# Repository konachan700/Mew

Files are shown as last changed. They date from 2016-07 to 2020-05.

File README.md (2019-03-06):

## Mew - hardware password manager


 

*   [Forum](https://forum.mewhpm.com)
*   [Wiki](https://wiki.mewhpm.com)
*   [Code repo (github)](https://github.com/konachan700/Mew)
*   [Code repo (gitlab mirror)](https://gitlab.com/mewhpm/Mew)
*   [Hardware](https://easyeda.com/konachan.700/MeW_Pro_v2.1)
*	[Android app sources](https://github.com/konachan700/Mew/tree/master/software/MeWSync)

##### • What is it?
It's a small USB device to hold your passwords, private keys and cryptowallets.

*   Easy to use.
*   Fully open sourced.
*   No drivers or propietary software required.
*   Highly protected for critical data.

 

##### • How does it work?

Connect MeW to a PC or mobile device. Pair MeW with your smartphone via bluetooth. Install the MeW HPM app from Google Play or Appstore. Use it.  

_Demo video will be here a bit later :3_

12 passwords, those you use more often, can be entered directly on the device. Other passwords could be entered by MeW HPM app.  

_Demo video will be here a bit later :3_

You can exchange public keys with your friends directly via bluetooth.

Technically, it is a HID-keyboard.

Passwords are not stored in the device, all passwords are generated on-the-fly depending on the entered PIN-code and internal master key. Nobody and nothing can steal your passwords database, because there is none. If anybody steals the device, he can't bruteforce it - for each PIN-code the device generate different passwords, and, if you set this option, fake logins will be shown.  

Your private keys and wallets, that are stored on the device, are encrypted with AES-256. Encryption key is generated from master key and pin-code on-the-fly. Master key has been stored internally and can't be extracted, of course, if you set the maximum security level.

##### • I lost my MeW. How can I get my passwords back?

When you are starting your MeW for the first time with normal security level, the device key will shown. Save the device key at a secure place. MeW has a cloud backup for encrypted master keys. For recovery of your passwords on a new device you have to enter a device key in the application, and enter you PIN-code in MeW.

In the high security mode cloud backup will disabled, because in this mode the encrypted master key i can't be extracted from the device. If you lose your MeW or forgot a PIN-code, you loose all you passwords.

## • Android application screenshots
&nbsp;&nbsp;&nbsp;&nbsp;&nbsp;&nbsp;&nbsp;&nbsp;&nbsp;&nbsp;&nbsp;&nbsp;

## • Device photos
&nbsp;&nbsp;&nbsp;&nbsp;

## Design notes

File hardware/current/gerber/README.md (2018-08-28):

### MeW HPM :: Gerber files
Ready for production gerber files. 

### Where am I see this gerber?
https://gerber-viewer.easyeda.com/

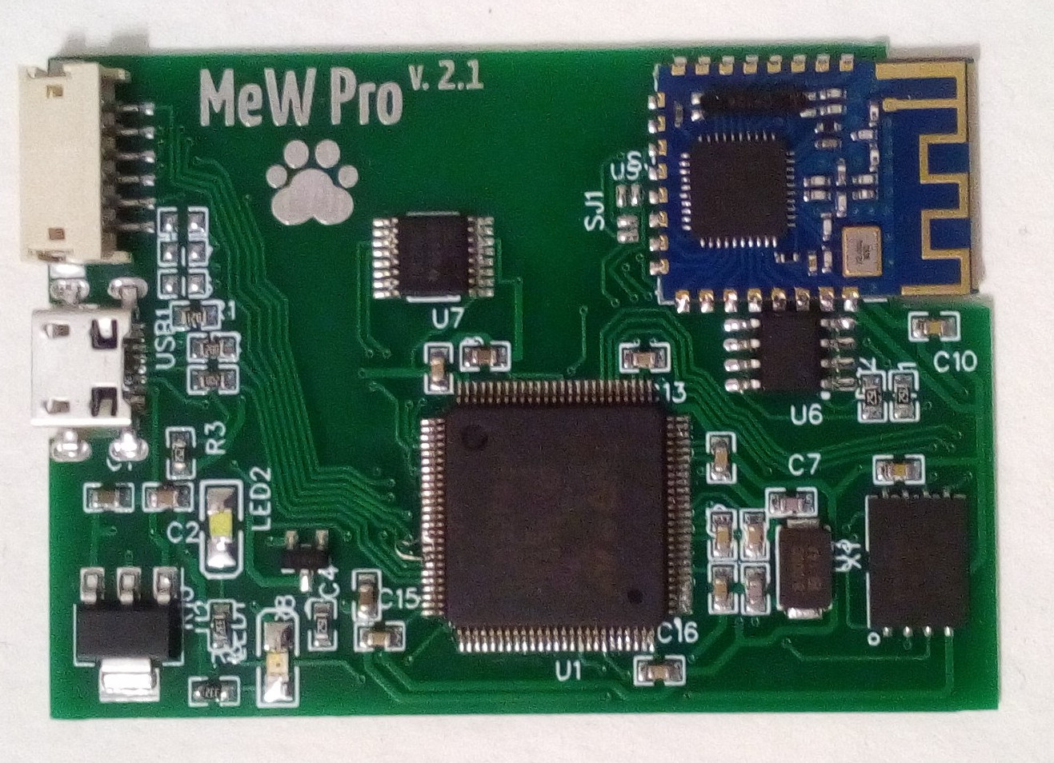
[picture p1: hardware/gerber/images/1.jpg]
Board image 1


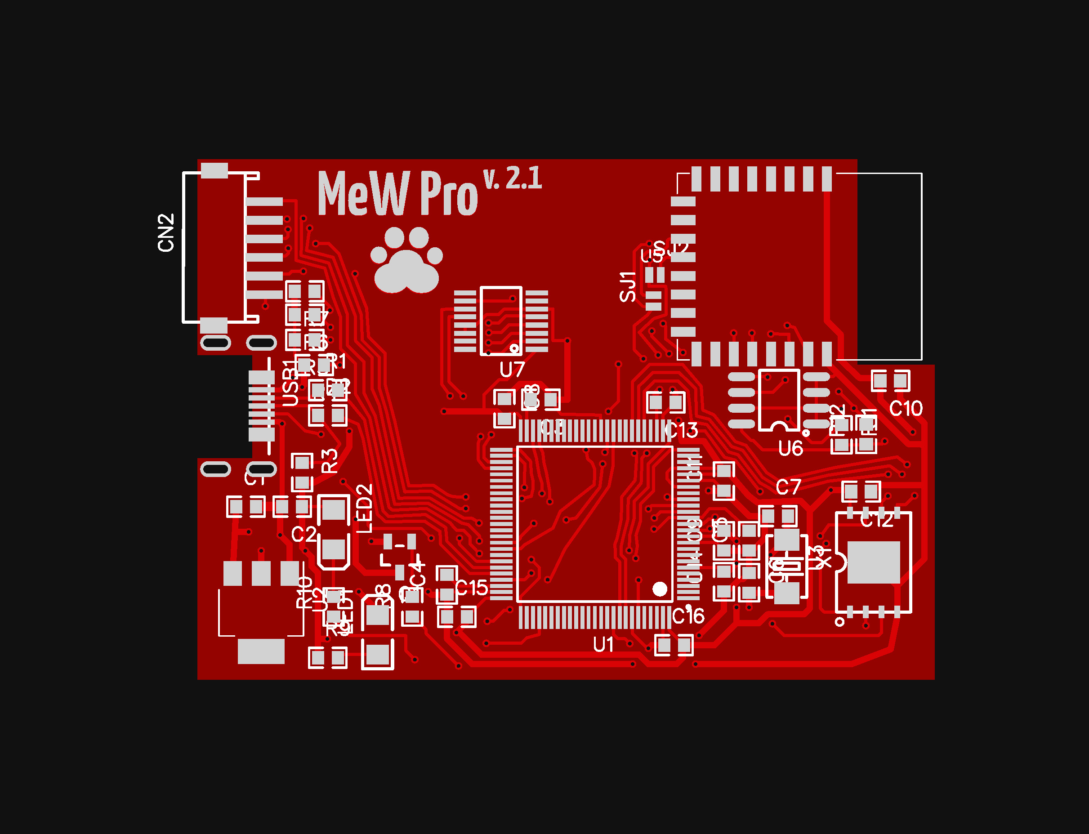
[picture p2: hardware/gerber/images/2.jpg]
Board image 2


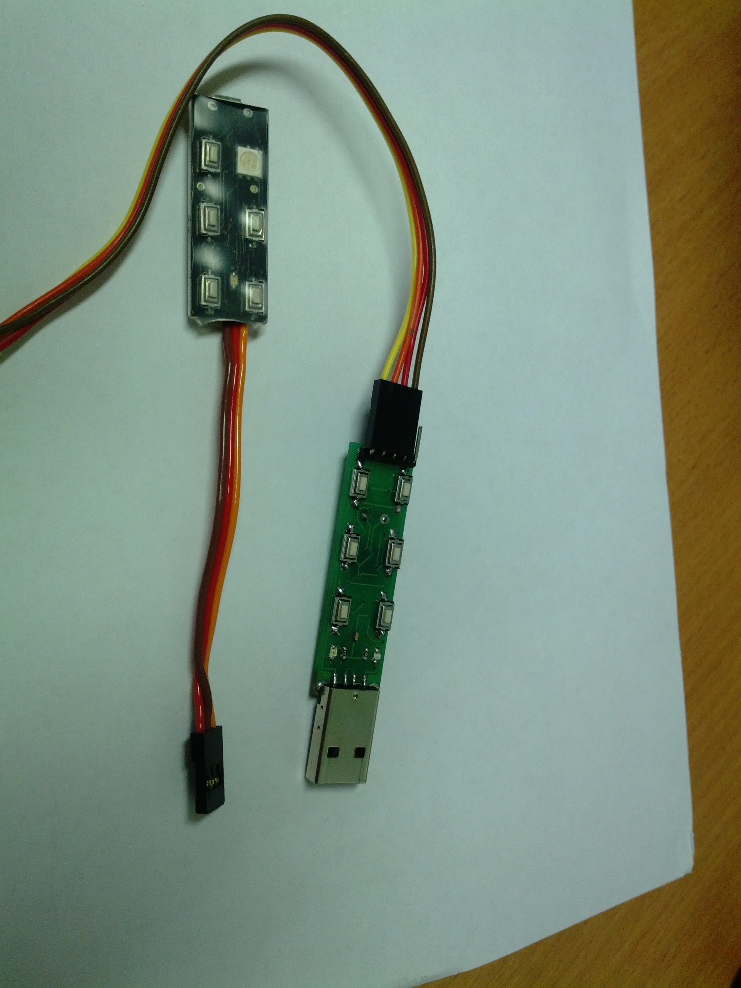
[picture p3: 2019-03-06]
promo/hardware/hw (3).jpg

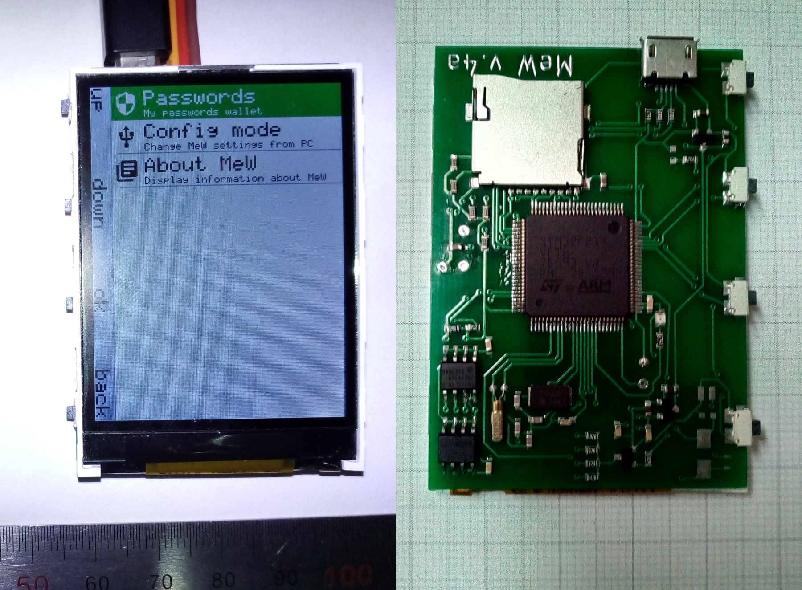
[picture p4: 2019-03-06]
promo/hardware/hw (1).jpg

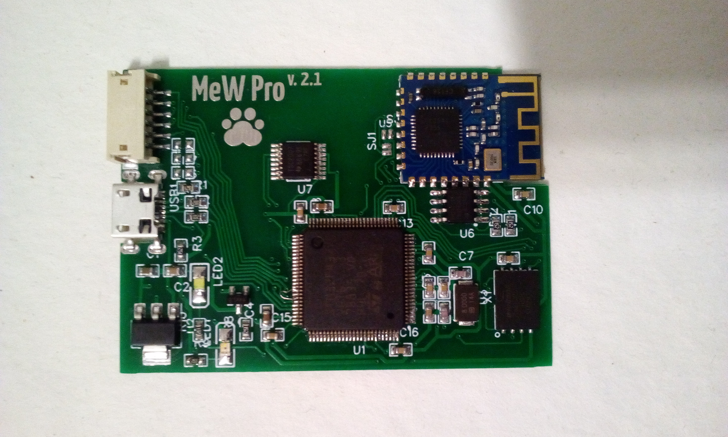
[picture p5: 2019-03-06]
promo/hardware/cameringo_20180814_204219.jpg

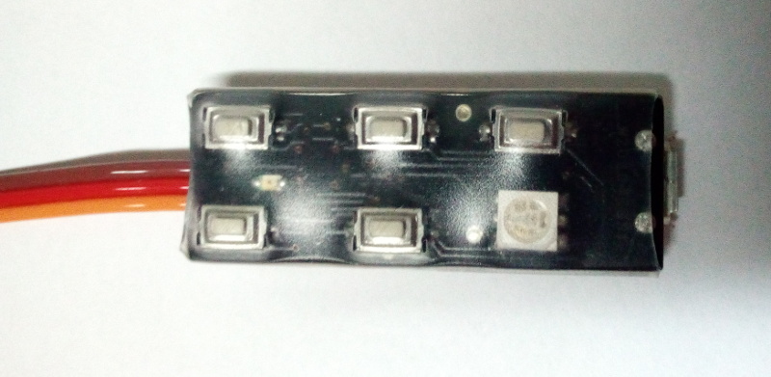
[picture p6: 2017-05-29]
promo/hardware/hw (4).jpg

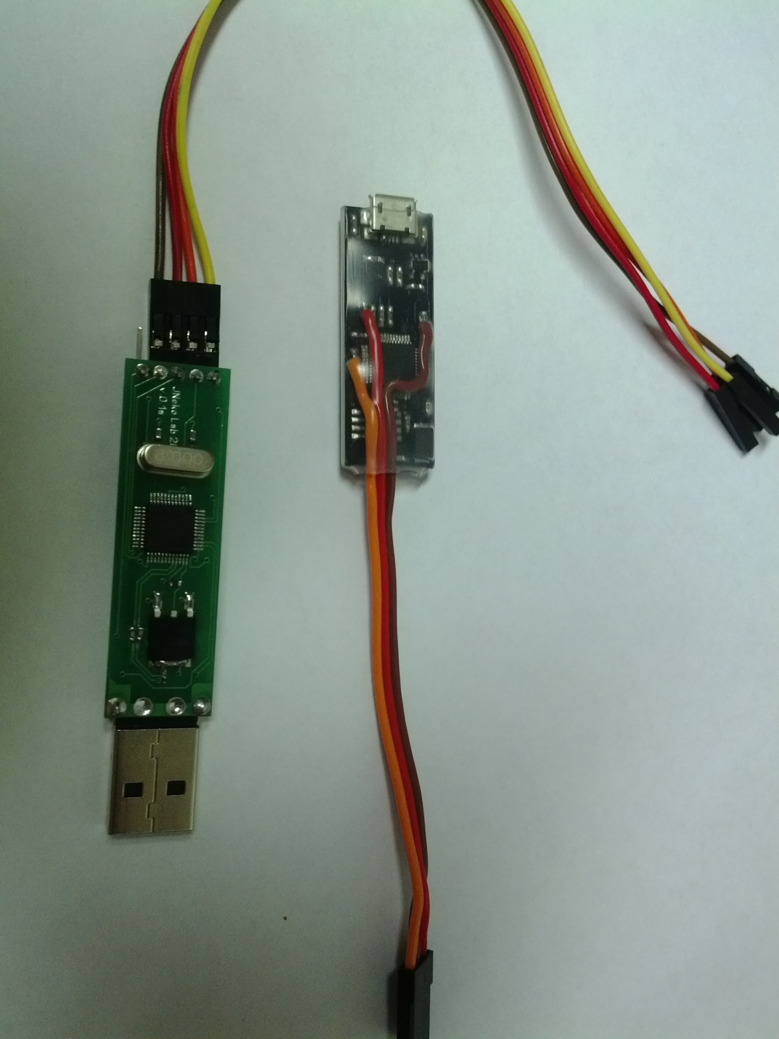
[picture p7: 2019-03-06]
promo/hardware/hw (2).jpg

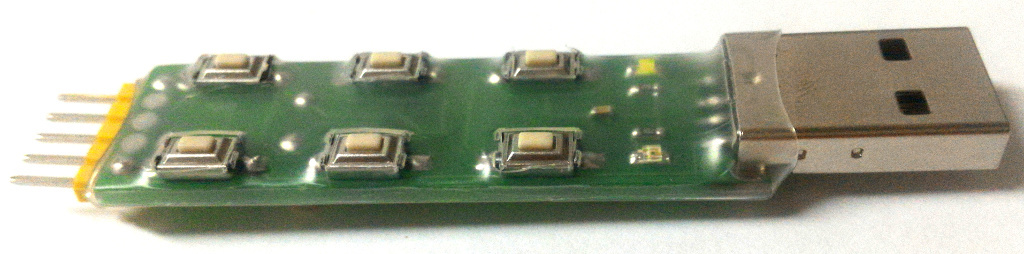
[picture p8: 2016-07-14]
promo/hardware/mewone-proto-01a.jpg

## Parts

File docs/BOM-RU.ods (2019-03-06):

В данном случае я считаю цену для покупки комплектухи поштучно в рознице. Оптовые цены, даже на небольших количествах (1000 штук) будут отличатся чуть ли не в 2-3 раза.
№ | Компонент | Модель | Кол-во | Цена, шт. | Цена, всего | Ссылка на магазин
MeW Pro A (Сенсорный экран, кнопки, bluetooth, батарея, 180MHz, 1M Rom, 256K Ram) || ЦЕНА РОЗНИЦЫ
1 | Контроллер | STM32F437VGT6 | 1 | р.1,050.00 | р.1,050.00 | https://www.electronshik.ru/item/ST/STM32F437VGT6
2 | Дисплей с сенсором | ILI9341 2.4' SPI 18Pin | 1 | р.313.04 | р.313.04 | https://www.aliexpress.com/item/2-4-Inch-240-320-SPI-Serial-TFT-LCD-Module-Display-With-Touch-Panel-Screen-ILI9341/32721841375.html
3 | Bluetooth | JDY-08 | 1 | р.112.00 | р.112.00 | https://www.aliexpress.com/item/10-pcs-JDY-08-BLE-Bluetooth-4-0-Uart-Transceiver-Module-CC2541-Central-Switching-Wireless-Module/32779065707.html
4 | Разьем карты памяти | NoName | 1 | р.7.69 | р.7.69 | https://www.aliexpress.com/item/10Pcs-TransFlash-TF-Micro-Memory-SD-Card-Self-eject-Socket-Plug-Adapter/32699668571.html
5 | Батарея LiIon | [L028] 3.7V 650mAh [303759] | 1 | р.79.38 | р.79.38 | https://www.aliexpress.com/item/L028-3-7V-620mAH-303759-PLIB-polymer-lithium-ion-battery-Li-ion-battery-for-bluetooth/711887876.html
6 | Micro USB Female Jack | NoName | 1 | р.3.21 | р.3.21 | https://www.aliexpress.com/item/100PCS-Lot-Micro-USB-Female-Jack-Socket-Connector-SMT-5Pin-5P-Long-feet-Gold-Plated/32735317426.html
7 | Выключатель питания* | MK12C02 7P-12608 | 1 | р.5.13 | р.5.13 | https://www.aliexpress.com/item/50PCS-Lot-MK12C02-7P-12608-MP3-MP4-Toggle-switch-Button-SMT-microswitch-KEY/32381680351.html
8 | Кнопки | 2 x 4 x 3.5mm | 5 | р.5.13 | р.25.65 | https://www.aliexpress.com/item/50pcs-2-x-4-x-3-5mm-Tact-Tactile-Push-Button-Switch-SMD-Surface-Mount-Momentary/32700051430.html
9 | Модуль зарядки батареи | TP4056 SOP-8 | 1 | р.4.49 | р.4.49 | https://www.aliexpress.com/item/200PCS-TP4056-SOP-TP4056E-SMD-new-and-original-IC/32874729556.html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
10 | Транзистор полевой | 2N7002K | 2 | р.2.57 | р.5.14 | https://www.aliexpress.com/item/Original-free-shipping-2N7002K-T1-E3-2N7002K-2N7002-SOT23-200PCS-LOT-in-Stock/32488438312.html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
11 | LDO | XC6206P332MR (уточнить) | 1 | р.1.29 | р.1.29 | https://www.aliexpress.com/item/100pcs-XC6206P332MR-XC6206P332-SOT23-XC6206-SMD-662K-3-3V-0-5A-SOT23-3-Positive-Fixed-LDO/32845735747.html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
12 | Резисторы** | (уточнить) | 10 | р.0.65 | р.6.50 | нет
13 | Конденсаторы** | (уточнить) | 10 | р.1.29 | р.12.90 | нет
14 | Светодиоды** | (уточнить) | 4 | р.0.65 | р.2.60 | нет
15 | Плата | NoName | 1 | р.12.41 | р.12.41 | нет
16 | Кварцевый резонатор | 8MHZ 5032 2P 8M | 1 | р.17.93 | р.17.93 | https://www.aliexpress.com/item/20PCS-8MHZ-5032-2P-8M-Crystal-5-3-2-2-feet/32841969827.html?priceBeautifyAB=0
17 | Кварцевый резонатор | 32.768KHz | 1 | р.3.85 | р.3.85 | https://www.aliexpress.com/item/100pcs-lot-Crystal-Cylinder-Cylinder-Clock-Crystal-Oscillator-32-768KHz-3x8MM-Passive-Quartz-Crystal-Resonator/1593653737.html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
ИТОГО |  |  |  |  | р.1,663.21
MeW Pro B (Сенсорный экран, кнопки, bluetooth, 168MHz, 1M Rom, 192K Ram) || ЦЕНА РОЗНИЦЫ
1 | Контроллер | STM32F407VGT6TR | 1 | р.582.00 | р.582.00 | https://www.electronshik.ru/item/ST/STM32F407VGT6TR
2 | Дисплей с сенсором | ILI9341 2.4' SPI 18Pin | 1 | р.313.04 | р.313.04 | https://www.aliexpress.com/item/2-4-Inch-240-320-SPI-Serial-TFT-LCD-Module-Display-With-Touch-Panel-Screen-ILI9341/32721841375.html
3 | Bluetooth | JDY-08 | 1 | р.112.00 | р.112.00 | https://www.aliexpress.com/item/10-pcs-JDY-08-BLE-Bluetooth-4-0-Uart-Transceiver-Module-CC2541-Central-Switching-Wireless-Module/32779065707.html
4 | Разьем карты памяти | NoName | 1 | р.7.69 | р.7.69 | https://www.aliexpress.com/item/10Pcs-TransFlash-TF-Micro-Memory-SD-Card-Self-eject-Socket-Plug-Adapter/32699668571.html
5 | Micro USB Female Jack | NoName | 1 | р.3.21 | р.3.21 | https://www.aliexpress.com/item/100PCS-Lot-Micro-USB-Female-Jack-Socket-Connector-SMT-5Pin-5P-Long-feet-Gold-Plated/32735317426.html
6 | Кнопки | 2 x 4 x 3.5mm | 5 | р.5.13 | р.25.65 | https://www.aliexpress.com/item/50pcs-2-x-4-x-3-5mm-Tact-Tactile-Push-Button-Switch-SMD-Surface-Mount-Momentary/32700051430.html
7 | Транзистор полевой | 2N7002K | 2 | р.2.57 | р.5.14 | https://www.aliexpress.com/item/Original-free-shipping-2N7002K-T1-E3-2N7002K-2N7002-SOT23-200PCS-LOT-in-Stock/32488438312.html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
8 | LDO | XC6206P332MR (уточнить) | 1 | р.1.29 | р.1.29 | https://www.aliexpress.com/item/100pcs-XC6206P332MR-XC6206P332-SOT23-XC6206-SMD-662K-3-3V-0-5A-SOT23-3-Positive-Fixed-LDO/32845735747.html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
9 | Резисторы** | (уточнить) | 7 | р.0.65 | р.4.55 | нет
10 | Конденсаторы** | (уточнить) | 7 | р.1.29 | р.9.03 | нет
11 | Светодиоды** | (уточнить) | 2 | р.0.65 | р.1.30 | нет
12 | Плата | NoName | 1 | р.12.41 | р.12.41 | нет
13 | Кварцевый резонатор | 8MHZ 5032 2P 8M | 1 | р.17.93 | р.17.93 | https://www.aliexpress.com/item/20PCS-8MHZ-5032-2P-8M-Crystal-5-3-2-2-feet/32841969827.html?priceBeautifyAB=0
ИТОГО |  |  |  |  | р.1,095.24
MeW Pro C (Сенсорный экран, кнопки, 168MHz, 1M Rom, 192K Ram) || ЦЕНА РОЗНИЦЫ
1 | Контроллер | STM32F407VGT6TR | 1 | р.582.00 | р.582.00 | https://www.electronshik.ru/item/ST/STM32F407VGT6TR
2 | Дисплей с сенсором | ILI9341 2.4' SPI 18Pin | 1 | р.313.04 | р.313.04 | https://www.aliexpress.com/item/2-4-Inch-240-320-SPI-Serial-TFT-LCD-Module-Display-With-Touch-Panel-Screen-ILI9341/32721841375.html
3 | Разьем карты памяти | NoName | 1 | р.7.69 | р.7.69 | https://www.aliexpress.com/item/10Pcs-TransFlash-TF-Micro-Memory-SD-Card-Self-eject-Socket-Plug-Adapter/32699668571.html
4 | Micro USB Female Jack | NoName | 1 | р.3.21 | р.3.21 | https://www.aliexpress.com/item/100PCS-Lot-Micro-USB-Female-Jack-Socket-Connector-SMT-5Pin-5P-Long-feet-Gold-Plated/32735317426.html
5 | Кнопки | 2 x 4 x 3.5mm | 5 | р.5.13 | р.25.65 | https://www.aliexpress.com/item/50pcs-2-x-4-x-3-5mm-Tact-Tactile-Push-Button-Switch-SMD-Surface-Mount-Momentary/32700051430.html
6 | Транзистор полевой | 2N7002K | 1 | р.2.57 | р.2.57 | https://www.aliexpress.com/item/Original-free-shipping-2N7002K-T1-E3-2N7002K-2N7002-SOT23-200PCS-LOT-in-Stock/32488438312.html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
7 | LDO | XC6206P332MR (уточнить) | 1 | р.1.29 | р.1.29 | https://www.aliexpress.com/item/100pcs-XC6206P332MR-XC6206P332-SOT23-XC6206-SMD-662K-3-3V-0-5A-SOT23-3-Positive-Fixed-LDO/32845735747.html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
8 | Резисторы** | (уточнить) | 5 | р.0.65 | р.3.25 | нет
9 | Конденсаторы** | (уточнить) | 5 | р.1.29 | р.6.45 | нет
10 | Светодиоды** | (уточнить) | 1 | р.0.65 | р.0.65 | нет
11 | Плата | NoName | 1 | р.12.41 | р.12.41 | нет
12 | Кварцевый резонатор | 8MHZ 5032 2P 8M | 1 | р.17.93 | р.17.93 | https://www.aliexpress.com/item/20PCS-8MHZ-5032-2P-8M-Crystal-5-3-2-2-feet/32841969827.html?priceBeautifyAB=0
ИТОГО |  |  |  |  | р.976.14
№ | Компонент | Модель | Кол-во | Цена, шт. | Цена, всего | Ссылка на магазин | № | Компонент | Модель | Кол-во | Цена, шт. | Цена, всего | Ссылка на магазин | № | Компонент | Модель | Кол-во | Цена, шт. | Цена, всего | Ссылка на магазин
MeW Pro A2 (Сенсорный экран, bluetooth, 180MHz, 1M Rom, 256K Ram, 128мб Flash) || ЦЕНА РОЗНИЦЫ |  |  |  |  |  |  | MeW Pro A (Сенсорный экран, кнопки, bluetooth, батарея, 180MHz, 1M Rom, 256K Ram) || ЦЕНА РОЗНИЦЫ |  |  |  |  |  |  | MeW Pro A (Сенсорный экран, кнопки, bluetooth, батарея, 180MHz, 1M Rom, 256K Ram) || ЦЕНА РОЗНИЦЫ
1 | Контроллер | STM32F437VGT6 | 1 | р.1,050.00 | р.1,050.00 | https://www.electronshik.ru/item/ST/STM32F437VGT6 | 1 | Контроллер | STM32F437VGT6 | 1 | р.1,050.00 | р.1,050.00 | https://www.electronshik.ru/item/ST/STM32F437VGT6 | 1 | Контроллер | STM32F437VGT6 | 1 | р.1,050.00 | р.1,050.00 | https://www.electronshik.ru/item/ST/STM32F437VGT6
2 | Дисплей с сенсором | ILI9341 2.4' SPI 18Pin | 1 | р.313.04 | р.313.04 | https://www.aliexpress.com/item/2-4-Inch-240-320-SPI-Serial-TFT-LCD-Module-Display-With-Touch-Panel-Screen-ILI9341/32721841375.html | 2 | Дисплей с сенсором | ILI9341 2.4' SPI 18Pin | 1 | р.313.04 | р.313.04 | https://www.aliexpress.com/item/2-4-Inch-240-320-SPI-Serial-TFT-LCD-Module-Display-With-Touch-Panel-Screen-ILI9341/32721841375.html | 2 | Дисплей с сенсором | ILI9341 2.4' SPI 18Pin | 1 | р.313.04 | р.313.04 | https://www.aliexpress.com/item/2-4-Inch-240-320-SPI-Serial-TFT-LCD-Module-Display-With-Touch-Panel-Screen-ILI9341/32721841375.html
3 | Bluetooth | JDY-08 | 1 | р.112.00 | р.112.00 | https://www.aliexpress.com/item/10-pcs-JDY-08-BLE-Bluetooth-4-0-Uart-Transceiver-Module-CC2541-Central-Switching-Wireless-Module/32779065707.html | 3 | Bluetooth | JDY-08 | 1 | р.112.00 | р.112.00 | https://www.aliexpress.com/item/10-pcs-JDY-08-BLE-Bluetooth-4-0-Uart-Transceiver-Module-CC2541-Central-Switching-Wireless-Module/32779065707.html | 3 | Bluetooth | JDY-08 | 1 | р.112.00 | р.112.00 | https://www.aliexpress.com/item/10-pcs-JDY-08-BLE-Bluetooth-4-0-Uart-Transceiver-Module-CC2541-Central-Switching-Wireless-Module/32779065707.html
4 | Micro USB Female Jack | NoName | 1 | р.3.21 | р.3.21 | https://www.aliexpress.com/item/100PCS-Lot-Micro-USB-Female-Jack-Socket-Connector-SMT-5Pin-5P-Long-feet-Gold-Plated/32735317426.html | 6 | Micro USB Female Jack | NoName | 1 | р.3.21 | р.3.21 | https://www.aliexpress.com/item/100PCS-Lot-Micro-USB-Female-Jack-Socket-Connector-SMT-5Pin-5P-Long-feet-Gold-Plated/32735317426.html | 6 | Micro USB Female Jack | NoName | 1 | р.3.21 | р.3.21 | https://www.aliexpress.com/item/100PCS-Lot-Micro-USB-Female-Jack-Socket-Connector-SMT-5Pin-5P-Long-feet-Gold-Plated/32735317426.html
5 | Транзистор полевой | 2N7002K | 2 | р.2.57 | р.5.14 | https://www.aliexpress.com/item/Original-free-shipping-2N7002K-T1-E3-2N7002K-2N7002-SOT23-200PCS-LOT-in-Stock/32488438312.html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 | 10 | Транзистор полевой | 2N7002K | 2 | р.2.57 | р.5.14 | https://www.aliexpress.com/item/Original-free-shipping-2N7002K-T1-E3-2N7002K-2N7002-SOT23-200PCS-LOT-in-Stock/32488438312.html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 | 10 | Транзистор полевой | 2N7002K | 2 | р.2.57 | р.5.14 | https://www.aliexpress.com/item/Original-free-shipping-2N7002K-T1-E3-2N7002K-2N7002-SOT23-200PCS-LOT-in-Stock/32488438312.html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
6 | LDO | AMS11133 | 1 | р.7.29 | р.7.29 |  | 11 | LDO | XC6206P332MR (уточнить) | 1 | р.1.29 | р.1.29 | https://www.aliexpress.com/item/100pcs-XC6206P332MR-XC6206P332-SOT23-XC6206-SMD-662K-3-3V-0-5A-SOT23-3-Positive-Fixed-LDO/32845735747.html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 | 11 | LDO | XC6206P332MR (уточнить) | 1 | р.1.29 | р.1.29 | https://www.aliexpress.com/item/100pcs-XC6206P332MR-XC6206P332-SOT23-XC6206-SMD-662K-3-3V-0-5A-SOT23-3-Positive-Fixed-LDO/32845735747.html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
7 | Резисторы** | (уточнить) | 10 | р.0.65 | р.6.50 | нет | 12 | Резисторы** | (уточнить) | 10 | р.0.65 | р.6.50 | нет | 12 | Резисторы** | (уточнить) | 10 | р.0.65 | р.6.50 | нет
8 | Конденсаторы** | (уточнить) | 10 | р.1.29 | р.12.90 | нет | 13 | Конденсаторы** | (уточнить) | 10 | р.1.29 | р.12.90 | нет | 13 | Конденсаторы** | (уточнить) | 10 | р.1.29 | р.12.90 | нет
9 | Светодиоды** | (уточнить) | 4 | р.0.65 | р.2.60 | нет | 14 | Светодиоды** | (уточнить) | 4 | р.0.65 | р.2.60 | нет | 14 | Светодиоды** | (уточнить) | 4 | р.0.65 | р.2.60 | нет
10 | Плата | NoName | 1 | р.12.41 | р.12.41 | нет | 15 | Плата | NoName | 1 | р.12.41 | р.12.41 | нет | 15 | Плата | NoName | 1 | р.12.41 | р.12.41 | нет
11 | Кварцевый резонатор | 8MHZ 5032 2P 8M | 1 | р.17.93 | р.17.93 | https://www.aliexpress.com/item/20PCS-8MHZ-5032-2P-8M-Crystal-5-3-2-2-feet/32841969827.html?priceBeautifyAB=0 | 16 | Кварцевый резонатор | 8MHZ 5032 2P 8M | 1 | р.17.93 | р.17.93 | https://www.aliexpress.com/item/20PCS-8MHZ-5032-2P-8M-Crystal-5-3-2-2-feet/32841969827.html?priceBeautifyAB=0 | 16 | Кварцевый резонатор | 8MHZ 5032 2P 8M | 1 | р.17.93 | р.17.93 | https://www.aliexpress.com/item/20PCS-8MHZ-5032-2P-8M-Crystal-5-3-2-2-feet/32841969827.html?priceBeautifyAB=0
12 | Модуль памяти 128мб |  | 1 | р.145.00 | р.145.00
13 | Контроллер сенсорного экрана |  | 1 | р.80.00 | р.80.00
ИТОГО |  |  |  |  | р.1,543.02 |  | ИТОГО |  |  |  |  | р.1,537.02 |  | ИТОГО |  |  |  |  | р.1,537.02

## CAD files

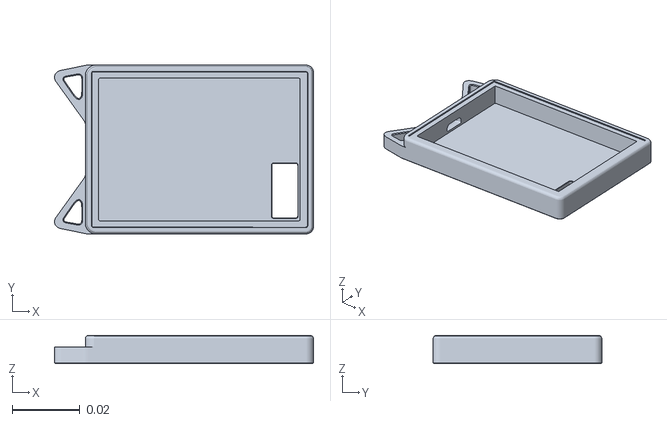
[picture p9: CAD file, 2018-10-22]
case/Case_mewboard_b.stl
0.0767 x 0.05 x 0.00832

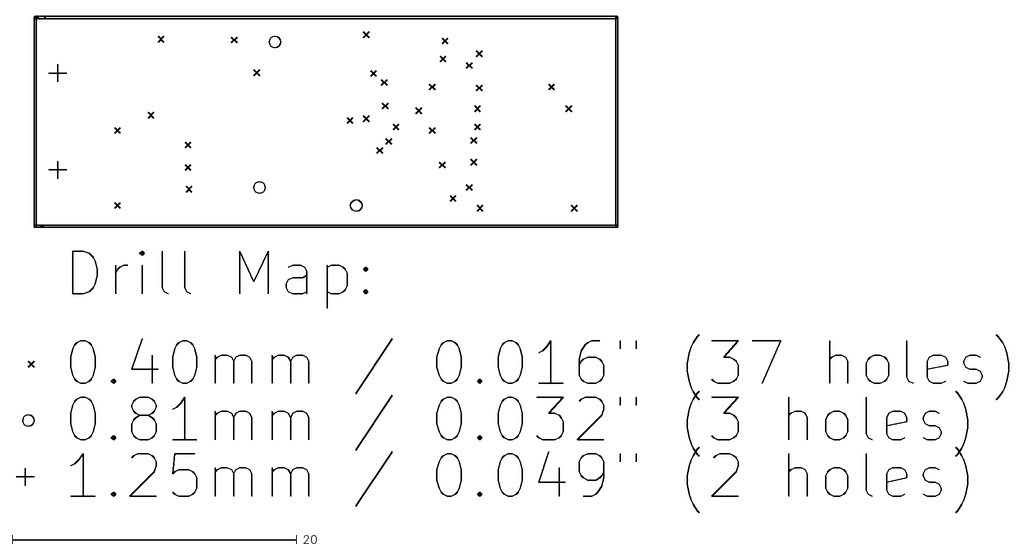
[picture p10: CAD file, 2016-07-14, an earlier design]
hardware/old-mew-one/kiCad/__test-drl_map.dxf
69.7 x 34.8

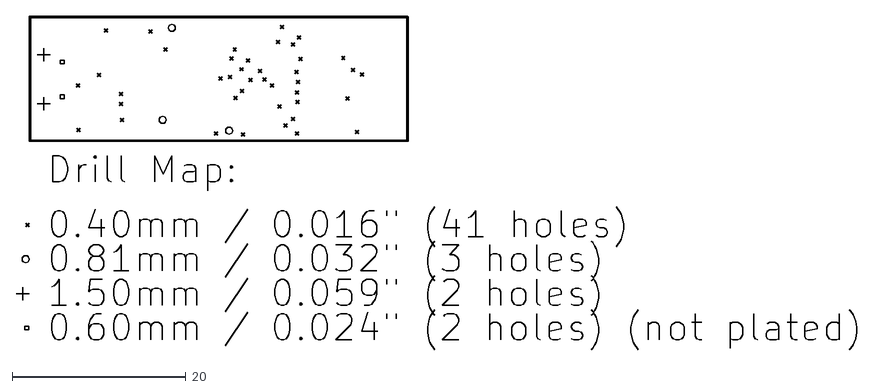
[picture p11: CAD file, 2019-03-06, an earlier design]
hardware/old-mew-one/kiCad/board_mew2/__test-drl_map.dxf
96.8 x 38.4

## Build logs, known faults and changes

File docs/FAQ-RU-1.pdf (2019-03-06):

Общий FAQ по техническому устройству.

Q: Можно ли приделать сканер отпечатков?
A: Можно. Однако есть проблемы.
1. Сканеров свободного назначения в продаже как-то не густо, и почти все они -огромные по размерам, предназначенные для установки на объектовых КПП. От телефонов поставить нельзя, документацию на него нам никто не даст, а без документации для написания драйверов это просто кусок пластмассы.
2. Безопасность бытовых сканеров отпечатков нулевая. Подделать отпечаток при наличии навыков задача очень простая.
3. Сканер отдает картинку. Обработка и сравнение отпечатка - очень сложная высшая математика, кода очень много. Часть можно взять из библиотек линукса, но в любом случае работы там очень много.

Q: Можно ли заменить нашим устройством токены для банк-клиентов?
A: Теоретически да. Технически все необходимое там есть. Но для такого токена нужна сертификация и куча лицензий от всех возможных регуляторов - иначе банк справедливо пошлет лесом самоделкиных.
Основа банковских токенов - доверие разработчику и ЦС. Рынок очень закрытый и консервативный по понятным причинам - какое доверие на проходном дворе? На старте сюда лезть полностью бесполезно.

Q: Почему нужно отдельное устройство? Почему не сделать приложение на телефон? A: Несколько проблем.
1. На андроид сделать такое приложение можно. Но для него нужен рут и сборка драйверов под конкретное ядро (то есть под конкретную модель телефона). Гемор страшный. На остальные устройства такое прикрутить нельзя.
2. Телефоны дырявы насквозь, и по ним не шарится только совсем ленивый. Даже для брендов, исключая разве что Apple, драйвера пишет индус за доллар в день - качество там ниже плинтуса, ехала уязвимость через уязвимость. Хакеры и спецслужбы могут отломить любой телефон и угнать базу паролей при первом желании. Какой смысл держать пароли в таком ненадежном месте?

Q: Зачем карта памяти? Почему не nand/eMMC?
A: Во-первых, хранить пароли, кошельки, другую инфу. Даже если устройство навернулось, мы можем переставить карту в другое и продолжать пользоваться. Данные зашифрованы, и такая операция безопасна. Во-вторых, карта стоит дешевле той же eMMC аналогичного размера, и на прототипах куда проще поставить карту, а не паять BGA.

Q: Сколько паролей влезает?
A: Для версий с картой - сколько угодно. Для простой версии - по количеству кнопок.

Q: Везде ли поддерживается?
A: Да, везде. По крайней мере там, где есть поддержка USB HID - а это любое устройство: телефон, игровая приставка, ТВ-приставка, ПК, Raspberry Pi, и прочее оборудование. Надо уточнять, однако, насчет телефонов Apple - возможно, нужен будет специальный переходник.

Q: Что понимать под поддержкой?
A: Принцип “устройство как сервис”
1. Есть две прошивки - одна открытая от сообщества, другая фирменная. Технически они почти одинаковы, но та, которая открытая, с официальными серверами не синхронизируется. Можно поднять свой сервер, но это реально будут делать 1 из 10 тысяч.
2. Синхронизация официальных устройств с сервером. Там хранится зашифрованная на пароль пользователя база, и ее кража для хакеров полностью бессмысленна.
3. Создание и поддержка SDK для написания приложений под официальную версию - чтобы самим не морочить голову написанием кошельков для криптовалют.
4. Приложения под все мобильные платформы и на десктоп.

Q: Какой функционал планируется в идеале?
A: Большой =)
1. Аппаратный менеджер паролей
2. Имитатор CD-ROM для установки ОС (если позволит скорость чипа)
3. Маленькая защищенная флешка
4. Неизвлекаемое хранилище
5. Цифровая подпись, совместимая с OpenSSL
6. Шифрование RSA и AES для различных нужд
7. TOTP
8. Криптовалютные кошельки
9. Тамагочи (шутка)

Q: А че такой похабный экран? Где IPS?
A: Хороших экранов в рознице нет, видимо, они поштучно никому не нужны. Все хорошие дисплеи от 4 дюймов размером, что для нашего устройства перебор. Есть маленькие oled, но стоят они очень дорого и не комплектуются сенсорными панелями. Если взлетит - можно поковырять алибабу и поискать приличный дисплей, сейчас обойдемся обычным TFT.

Q: Можно ли заказать 2-3 штуки плат для тестов?
A: Можно. Но сэкономить не выйдет.
1. Платы что 2, что 10 стоят одинаково 2 бакса
2. Под плату нужен трафарет, стальной лист 20 х 30. Без него запайка превращается в производство брака. Я с трудом запаял без трафарета маленькую версию, большую вообще не реально запаять, не перегрев всё подряд.
3. Заказ делается неделю и идет месяц-полтора.
UPD 31-05-18: Платы и трафареты подешевели, комплект с доставкой стоит $20.

Q: Не украдут ли китайцы? Какую защиту прикрутить?
A: Обязательно украдут. Это неизбежно и сделать ничего нельзя: чувак на хабре вон ради шутки сделал абсолютно бесполезный usb-killer для порчи портов - так через год оно на али появилось в куче мест. Зачем? Китаец увидел - китаец сделал, а рынок сам определит зачем. Потому надо изначально понять, как от китайских клонов получить выгоду, а не убыток. Прикручивать защиту бесполезно, даже вредно: китаец просто сделает аналог, а не клон, и тогда профит с него не поиметь никак.

Q: Что такое индексы A, B, C у MeW Pro?
A: Плата изначально была запроектирована универсальной. Различия такие:
1. Модель A. Максимальная, есть все оборудование. Эта модель основная.
2. Модель B. Без батареи и с более слабым контроллером (но незначительно). Батарея не сильно нужна в большинстве применений такого устройства, потому аппарат без нее имеет право на существование.
3. Модель C. Это модель B, но без bluetooth. Опять же, многим он не нужен.

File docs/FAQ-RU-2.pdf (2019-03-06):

Общий FAQ по использованию устройства.

Q: Я потерял устройство. Другой его нашел. Что делать?
A: Моделей защиты несколько, они будут выбиратся:
1. Пароли на устройстве создаются “на лету” из пин-кода пользователя и внутреннего ключа при помощи алгоритмов хеширования. То есть от каждого возможного пин-кода будет свой пароль. Нашедший устройство просто не будет знать, какой пин-кода верный, устройство для всех пин-кодов отдает пароли, но для неверного пин-кода будет и пароль неправильный. Эта модель позволяет иметь несколько банок паролей на одном устройстве, вводя разные пин-коды.
2. Тоже самое, что в п.1, но ключа уже два: для правильного пин-кода и для остальных. Дополнительно в устройстве сохраняется хеш правильного пин-кода. Дальше, например, при 4 попытках неверного ввода устройство изменит ключ правильного пин-кода, от которого создавались пароли - даже если злоумышленник угадает пин-код перебором, пароли он получит неправильные.
3. Просто пин-код и 3 попытки его ввода. Не угадал - ключ стерся.

Q: Меня взяли за задницу преступники, и они просят пин-код. Что делать?
A: Устройство имеет пин-коды для полного стирания памяти. Их набор гарантированно сменит пароли, после чего можно будет отдать настоящий пин-код - твоих паролей там не будет, да и привязка к облаку отвалится. Если такое устройство попробовать синхронизировать без сброса в аккаунте - бекап будет заблокирован.

Q: У меня в почте зашифрованная переписка, содержащая неоднозначные или не одобряемые обществом вещи. Кто-то из родственников может знать мой пин-код, подсмотрев набор. Как быть?
A: Устройство поддерживает динамические пин-коды:
1. Каждый раз разный пин-код, метод генерации которого задается в настройках. Например, сегодня 1.01 и пинкод будет 777101, а завтра он будет 777201. Пусть подглядывают.
2. Пин-код из большого набора изображений, из которых надо выделить тег. Например, 16 картинок котят, в которых надо тапнуть по порядку только белых с черным пятном. Поскольку никто не знает, по какому принципу идет выборка котят, отгадать такой пин-код подсмотревшему почти невозможно - картинок котят всего 256 штук и выводятся они случайно по 16 штук.

Q: Я укурился\набухался и боюсь, что начну использовать устройство в нетрезвом виде. Как быть?
A: Устройство имеет временную блокировку от использования. Устройство отключается специальным пин-кодом и восстанавливается только в установленное время после синхронизации с облаком.

Q: Я имею очень важные или секретные данные, которые даже зашифрованными нельзя класть в облако. Как быть?
A: Устройство имеет несколько уровней безопасности:
1. Параноидальный. Динамический пин-код с двумя попытками ввода. Синхронизация с облаком отключена, ключ шифрования памяти использует пин-код и внутренний ключ. Флешка дополнительно запаролена аппаратно, то есть снять с нее даже зашифрованный бекап нельзя - для любого другого устройства она выглядит как неисправная. При любой тревоге (введен пин-код стирания, неверный ввод пин-кода) происходит не только стирание ключей, но и полный снос прошивки, а также стирание карты. Если с устройством что-то случилось - восстановление базы невозможно.
2. Максимальный. В нем дается три попытки на ввод пин-кода, синхронизация с облаком отключена, ключ шифрования памяти использует пин-код и внутренний ключ. Взлом такого устройства невозможен даже с использованием человеческого фактора, однако поломка, утеря или сбой приведут к полной потере всего содержимого. Бекапить флешку тоже бесполезно, так как ключ от нее будет неизвлекаемым.
3. Средний. Файлы в облаке зашифрованы на хеш от пин-кода пользователя, память тоже. Внутренний ключ для шифрования не используется. При утере, порче или сбое устройство легко восстановить, однако хищение пин-кода даст возможность взлома базы.

Q: Я слышал, что можно прочесть память контроллера через технологические режимы или баги в реализации бит защиты...
A: Информации о взломе STM32F4 нет, и скорее всего, бекдор тоже не существует. Прочитать память можно, но делают это в десятке лабораторий в мире, стоить это будет сотни тысяч долларов, да и у атакующего будет одна попытка с вероятностью успеха процентов в 25. Можно считать, что устройства достаточно защищены для использования на гражданке.

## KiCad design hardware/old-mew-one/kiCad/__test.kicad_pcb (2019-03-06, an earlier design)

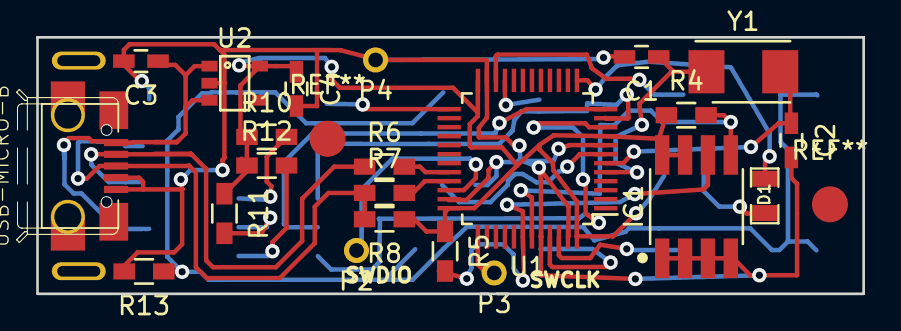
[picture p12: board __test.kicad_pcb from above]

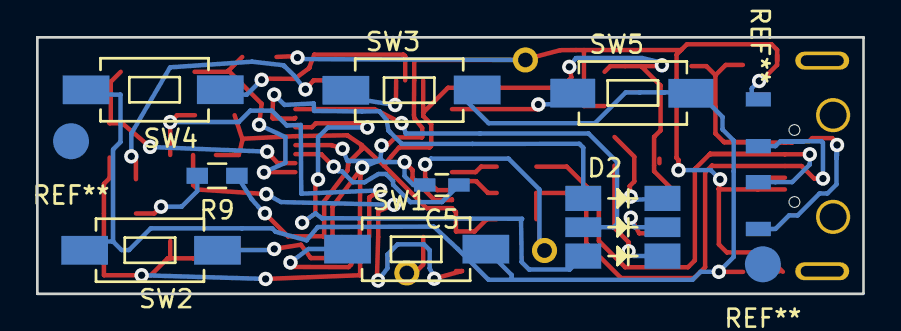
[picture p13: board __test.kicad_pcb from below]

Board: 2 copper layers, 45.9 x 14.2 mm, 30 parts (8 on the bottom side), 28 nets.

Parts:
C1, C2: 22; C_0603_HandSoldering
C3: 100nf; C_0603_HandSoldering
C4: 1mf; C_0603_HandSoldering
C5: 0.1mf; C_0603_HandSoldering
CON1: USB-MICRO-B; USB_MICRO_B_SMD
D1: YELLOW; SM0805
D2: LED_RGB_0505; LED_5050_RGB
IC1: ATSHA204A; SO-8_EP1
P2: 1; CONN_2.54mm_1x1
P3: 3; CONN_2.54mm_1x1
P4: 2; CONN_2.54mm_1x1
R4, R5: 1k2; R_0603_HandSoldering
R6, R7: 22; R_0603_HandSoldering
R8, R10, R11, R12: 1k5; R_0603_HandSoldering
R9: 1k; R_0603_HandSoldering
R13: 330; R_0603_HandSoldering
SW1, SW2, SW3, SW4, SW5: SW_PUSH; SW_SPST_EVQPE1
U1: STM32F103C8; LQFP-48_7x7mm_Pitch0.5mm
U2: TLV70033DDC; SOT-23-5
Y1: Crystal; Crystal_SMD_5032_2Pads

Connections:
+3V3: C4.1, IC1.8, R4.1, R5.1, R8.1, R9.1, R10.1, R11.1, R12.1, U1.9, U1.24, U1.36, U1.48, U2.5
/BTN_1: SW1.1, U1.45
/BTN_2: SW2.1, U1.46
/BTN_3: SW3.1, U1.21
/BTN_4: SW4.1, U1.22
/BTN_5: SW5.1, U1.25
/I2C_SCL_1: IC1.6, R5.2, U1.42
/I2C_SDA_1: IC1.5, R4.2, U1.43
/LED_B: D2.3, U1.10
/LED_G: D2.2, U1.12
/LED_R: D2.1, U1.11
/LED_READY: D1.1, U1.13
/SWCLK: P3.1, U1.37
/SWDIO: P2.1, U1.34
/USB_DM: R6.2, U1.32
/USB_DP: R7.2, U1.33
GND: C1.2, C2.2, C3.2, C4.2, C5.2, CON1.4, IC1.4, P4.1, R13.2, U1.8, U1.23, U1.35, U1.44, U1.47, U2.2
unnamed: C1.1, U1.5, Y1.1
unnamed: C2.1, U1.6, Y1.2
unnamed: C3.1, CON1.1, U2.1, U2.3
unnamed: C5.1, U1.7
unnamed: D1.2, R9.2
unnamed: D2.4, R12.2
unnamed: D2.5, R11.2
unnamed: D2.6, R10.2
unnamed: CON1.2, R6.1
unnamed: CON1.3, R7.1, R8.2
unnamed: R13.1, SW1.2, SW2.2, SW3.2, SW4.2, SW5.2

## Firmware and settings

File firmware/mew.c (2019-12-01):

// base headers
#include "mew.h"
#include "debug.h"
// drivers
#include "drivers/duart/duart.h"
#include "drivers/usb/mew_usb_hid.h"
#include "drivers/bluetooth/bluetooth.h"
#include "drivers/system/system.h"
#include "drivers/spi_flash/flash.h"
#include "drivers/i2c/i2c.h"
#include "drivers/flash/flash.h"
#include "drivers/display/display.h"
#include "drivers/hw_crypt/P256-cortex-ecdh.h"
// application modules
#include "app/packet_parser/parser.h"
// ui modules
#include "ui/ui.h"

static volatile unsigned long _mew_loop_counter = 0;

const mew_driver drivers[] = {
    {
        MEW_DRIVER_ID_CLOCK, 
        "STM32F4 System clock",
        &mew_clock_init, 
        NULL,
    }, {
        MEW_DRIVER_ID_DUART, 
        "\n\n-------- STM32F4 Debug usart started --------",
        &mew_init_duart, 
        NULL,
    }, {
        MEW_DRIVER_ID_SYSTICK, 
        "STM32F4 Systick",
        &mew_systick_init, 
        NULL,
    }, {
        MEW_DRIVER_ID_USB_HID_KB, 
        "USB HID keyboard",
        &mew_hid_usb_init, 
        NULL,
    }, {
		MEW_DRIVER_ID_RNG,
		"Hardware random number generator",
		&mew_rng_init,
		NULL
	}, {
		MEW_DRIVER_ID_P256_ECDH,
		"P-256 ECDH Keypair generator",
		&mew_p256_ecdh_handler,
		&mew_p256_ecdh_test
	}, {
        MEW_DRIVER_ID_BLUETOOTH, 
        "BLE module HM-11",
        &mew_bluetooth_init, 
        NULL
    }, {
        MEW_DRIVER_ID_SPI_FLASH,
        "128 MBytes spi flash",
        &mew_spi_flash_init,
        NULL
    }, {
        MEW_DRIVER_ID_I2C,
        "STM32F4 I2C",
        &mew_i2c_init,
        NULL // &mew_i2c_eeprom_test - this test will corrupt your data in the eeprom
    }, {
		MEW_DRIVER_ID_OTP_STORAGE,
		"MeW ID OTP storage",
		&mew_otp_storage_init,
		NULL
	}, {
    	MEW_DRIVER_ID_SEC_EEPROM,
		"Encrypted eeprom for settings",
		&mew_load_secure_settings,
		NULL
	}, {
        MEW_DRIVER_ID_DISPLAY,
        "2.4' TFT SPI display",
        &mew_display_init,
        NULL //&mew_ui_show_pinpad
    }, {
        MEW_DRIVER_ID_TOUCHSCREEN,
        "Resistive touchscreen with hardware controller",
        &mew_touchscreen_init,
        NULL
    }, {
        0
    }
};

const mew_loop_handler loop_handlers[] = {
    {
			MEW_LHANDLER_ID_PACKAGE_PARSER,
			"Stream to packages parser",
			&mew_comm_handler
    }, /*{
    		MEW_LHANDLER_ID_BLUETOOTH,
			"Bluetooth at-terminal",
			&mew_bluetooth_handler
    },*/ {
    		MEW_LHANDLER_ID_UI,
			"UI logic handle",
			&mew_ui_lhandler
	}, {
			MEW_LHANDLER_ID_LVGL,
			"LVGL handle",
			&mew_lvgl_lhandler
    }, {
    		MEW_LHANDLER_ID_SPI_FLASH,
			"SPI Flash async read/write handler",
			&mew_spi_flash_handler
	}, {
        0
    }
};

int main(void) {
    unsigned int i = 0;
    const mew_driver *drv;
    const mew_loop_handler *loop_handler;
    
    // init all drivers
    while(1) {
        drv = &drivers[i];
        if (drv->id == 0) {
            break;
        }

        if (drv->init() != 0) {
            mew_debug_die_with_message(drv->display_name);
        } else {
            mew_debug_print(drv->display_name);
        }
        
        i++;
    }
    
    // devices test 
    i = 0;
    while (1) {
        drv = &drivers[i];
        if (drv->id == 0) {
            break;
        }
        
        if (drv->test != NULL) {
            drv->test();
        }
        
        i++;
    }

    // main loop
    while(1) {
        i = 0;
        while(1) {
            loop_handler = &loop_handlers[i];
            if (loop_handler->id == 0) {
                break;
            }
            
            if (loop_handler->handler() != 0) {
                mew_debug_die_with_message(loop_handler->display_name);
            }
            
            i++;
        }
        _mew_loop_counter++;
    }
    return 1;
}

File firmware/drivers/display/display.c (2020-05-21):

#include "display.h" 
#include "debug.h"
#include "../system/system.h"

#define MEW_GD_BUF_SIZE ((LV_HOR_RES_MAX * LV_VER_RES_MAX) / 8)

static void __mew_wait(void);
static void __mew_cmd(void);
static void __mew_data(void);
static void __mew_unselect(void);

static void __mew_init_control_pins(void);
static void __mew_init_spi_pins(void);
static void __mew_spi_init_non_dma(void);
static void __mew_display_init(void);

static void __mew_display_write_cmd(uint16_t cmd);
static void __mew_display_write_cmd_with_data(uint16_t cmd, uint16_t* data, uint16_t size);

static volatile uint8_t _mew_dma_rx_state = 0;

static lv_disp_buf_t 	_mew_disp_buf;
static lv_color_t 		_mew_gd_buf[MEW_GD_BUF_SIZE];
static lv_disp_drv_t * 	_mew_current_disp = NULL;

static void __mew_wait(void) {
    uint16_t i;
    for (i=0; i<128; i++) __asm__("NOP");
}

static void __mew_data(void) {
    gpio_clear(MEW_DISPLAY_CS_PORT, MEW_DISPLAY_CS_PIN);
    gpio_set(MEW_DISPLAY_DC_PORT, MEW_DISPLAY_DC_PIN);
    __mew_wait();
}

static void __mew_cmd(void) {
    gpio_clear(MEW_DISPLAY_CS_PORT, MEW_DISPLAY_CS_PIN);
    gpio_clear(MEW_DISPLAY_DC_PORT, MEW_DISPLAY_DC_PIN);
    __mew_wait();
}

static void __mew_unselect(void) {
    gpio_set(MEW_DISPLAY_CS_PORT, MEW_DISPLAY_CS_PIN);
    gpio_set(MEW_DISPLAY_DC_PORT, MEW_DISPLAY_DC_PIN);
    __mew_wait();
}

static void __mew_display_write_cmd(uint16_t cmd) {
    __mew_cmd();
    spi_send(MEW_DISPLAY_SPI, cmd);
    __mew_wait();
    //__mew_unselect();
}

static void __mew_display_write_cmd_with_data(uint16_t cmd, uint16_t* data, uint16_t size) {
    uint16_t i;
    __mew_cmd();
    spi_send(MEW_DISPLAY_SPI, cmd);
    __mew_wait();
    __mew_data();
    for (i=0; i<size; i++) {
        spi_send(MEW_DISPLAY_SPI, data[i]);
    }
    __mew_wait();
    //__mew_unselect();
}

static void __mew_display_init(void) {
    gpio_clear(MEW_DISPLAY_RESET_PORT, MEW_DISPLAY_RESET_PIN);
    mew_delay_ms(10);
    gpio_set(MEW_DISPLAY_RESET_PORT, MEW_DISPLAY_RESET_PIN);
    mew_delay_ms(50);
    
    __mew_display_write_cmd(0x01);
    mew_delay_ms(50);
    __mew_display_write_cmd(0x28);
    
    __mew_display_write_cmd_with_data(0xCB, (uint16_t[]) { 0x39,0x2C,0x00,0x34,0x02 }, 5);
    __mew_display_write_cmd_with_data(0xCF, (uint16_t[]) { 0x00,0xC1,0x30 }, 3);
    __mew_display_write_cmd_with_data(0xE8, (uint16_t[]) { 0x85,0x00,0x78 }, 3);
    __mew_display_write_cmd_with_data(0xEA, (uint16_t[]) { 0x00,0x00 }, 2);
    __mew_display_write_cmd_with_data(0xED, (uint16_t[]) { 0x64,0x03,0x12,0x81 }, 4);
    __mew_display_write_cmd_with_data(0xF7, (uint16_t[]) { 0x20 }, 1);
    __mew_display_write_cmd_with_data(0xC0, (uint16_t[]) { 0x23 }, 1);
    __mew_display_write_cmd_with_data(0xC1, (uint16_t[]) { 0x10 }, 1);
    __mew_display_write_cmd_with_data(0xC5, (uint16_t[]) { 0x3e,0x28 }, 2);
    __mew_display_write_cmd_with_data(0xC7, (uint16_t[]) { 0x86 }, 1);
    __mew_display_write_cmd_with_data(0x36, (uint16_t[]) { 0x9C }, 1); // bit 4 - RGB/BGR  0101 1010
    __mew_display_write_cmd_with_data(0x3A, (uint16_t[]) { 0x55 }, 1);
    __mew_display_write_cmd_with_data(0xB1, (uint16_t[]) { 0x00,0x18 }, 2);
    __mew_display_write_cmd_with_data(0xB6, (uint16_t[]) { 0x08,0x82,0x27 }, 3);
    __mew_display_write_cmd_with_data(0xF2, (uint16_t[]) { 0x00 }, 1);
    __mew_display_write_cmd_with_data(0x26, (uint16_t[]) { 0x01 }, 1);
    __mew_display_write_cmd_with_data(0xE0, (uint16_t[]) { 0x0F,0x31,0x2B,0x0C,0x0E,0x08,0x4E,0xF1,0x37,0x07,0x10,0x03,0x0E,0x09,0x00 }, 15);
    __mew_display_write_cmd_with_data(0xE1, (uint16_t[]) { 0x00,0x0E,0x14,0x03,0x11,0x07,0x31,0xC1,0x48,0x08,0x0F,0x0C,0x31,0x36,0x0F }, 15);
    __mew_display_write_cmd_with_data(0x33, (uint16_t[]) { 0x00,0x00,0x01,0x40,0x00,0x00 }, 6);
    __mew_display_write_cmd_with_data(0x37, (uint16_t[]) { 0x00,0x00 }, 2);
    __mew_display_write_cmd_with_data(0x53, (uint16_t[]) { 0x20 }, 1);
    __mew_display_write_cmd_with_data(0x51, (uint16_t[]) { 0xFF }, 1);

    __mew_display_write_cmd(0x11);
    mew_delay_ms(100);
    __mew_display_write_cmd(0x29);
    mew_delay_ms(20);
}

static void __mew_init_control_pins(void) {
    gpio_mode_setup(MEW_DISPLAY_RESET_PORT, GPIO_MODE_OUTPUT, GPIO_MODE_OUTPUT, MEW_DISPLAY_RESET_PIN);
    gpio_set_output_options(MEW_DISPLAY_RESET_PORT, GPIO_OTYPE_PP, GPIO_OSPEED_25MHZ, MEW_DISPLAY_RESET_PIN);
    
    gpio_mode_setup(MEW_DISPLAY_DC_PORT, GPIO_MODE_OUTPUT, GPIO_MODE_OUTPUT, MEW_DISPLAY_DC_PIN);
    gpio_set_output_options(MEW_DISPLAY_DC_PORT, GPIO_OTYPE_PP, GPIO_OSPEED_25MHZ, MEW_DISPLAY_DC_PIN);
    
    gpio_mode_setup(MEW_DISPLAY_CS_PORT, GPIO_MODE_OUTPUT, GPIO_MODE_OUTPUT, MEW_DISPLAY_CS_PIN);
    gpio_set_output_options(MEW_DISPLAY_CS_PORT, GPIO_OTYPE_PP, GPIO_OSPEED_25MHZ, MEW_DISPLAY_CS_PIN);
    
    gpio_mode_setup(MEW_DISPLAY_BL_PORT, GPIO_MODE_OUTPUT, GPIO_MODE_OUTPUT, MEW_DISPLAY_BL_PIN);
    gpio_set_output_options(MEW_DISPLAY_BL_PORT, GPIO_OTYPE_PP, GPIO_OSPEED_100MHZ, MEW_DISPLAY_BL_PIN);
    gpio_set(MEW_DISPLAY_BL_PORT, MEW_DISPLAY_BL_PIN);
}

static void __mew_init_spi_pins(void) {
    gpio_mode_setup(MEW_DISPLAY_SPI_GPIO_PORT, GPIO_MODE_AF, GPIO_PUPD_NONE, MEW_DISPLAY_SPI_GPIO_PINS);
    gpio_set_output_options(MEW_DISPLAY_SPI_GPIO_PORT, GPIO_OTYPE_PP, GPIO_OSPEED_100MHZ, MEW_DISPLAY_SPI_GPIO_PINS);
    gpio_set_af(MEW_DISPLAY_SPI_GPIO_PORT, MEW_DISPLAY_SPI_GPIO_AF_NUMBER, MEW_DISPLAY_SPI_GPIO_PINS);
}

static void __mew_spi_init_non_dma(void) {
    nvic_disable_irq(MEW_DISPLAY_DMA_NVIC);
    spi_disable(MEW_DISPLAY_SPI);
    spi_set_master_mode(MEW_DISPLAY_SPI);
    spi_set_baudrate_prescaler(MEW_DISPLAY_SPI, SPI_CR1_BR_FPCLK_DIV_4);
    spi_set_clock_polarity_0(MEW_DISPLAY_SPI);
    spi_set_clock_phase_0(MEW_DISPLAY_SPI);
    spi_set_unidirectional_mode(MEW_DISPLAY_SPI);
    //spi_set_bidirectional_transmit_only_mode(DISPLAY_SPI);
    spi_enable_software_slave_management(MEW_DISPLAY_SPI);
    spi_send_msb_first(MEW_DISPLAY_SPI);
    spi_set_nss_high(MEW_DISPLAY_SPI);
    spi_disable_tx_buffer_empty_interrupt(MEW_DISPLAY_SPI);
    spi_disable_rx_buffer_not_empty_interrupt(MEW_DISPLAY_SPI);
    spi_disable_error_interrupt(MEW_DISPLAY_SPI);
    spi_disable_tx_dma(MEW_DISPLAY_SPI);
    spi_disable_rx_dma(MEW_DISPLAY_SPI);
    spi_set_dff_8bit(MEW_DISPLAY_SPI);
    spi_send_msb_first(MEW_DISPLAY_SPI);
    spi_enable(MEW_DISPLAY_SPI);
}
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

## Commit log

2016-07-14 Inital commit
    [__test-drl_map.dxf, __test.kicad_pcb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]
2016-08-03 add firmware v.0.3, based on opencm3
    [__test-drl_map.dxf, __test.kicad_pcb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]
2016-08-04 Убрал баг с платы
    На второй плате обнаружился баг, забыл развести конденсатор на reset и
    замкнуть ноги 4-5 usb-разъема. Заодно сделал универсальным посадочное
    место SO8, теперь туда можно припаять как ATHSA204A, так и 24cXX eeprom.
    [__test-drl_map.dxf, __test.kicad_pcb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]
2016-08-14 Мелкая правка платы
    Поставил чуть другие кнопки, тех не найти.
    Поставил реперы.
    [MeW.kicad_pcb, MeW.sch, __test-drl_map.dxf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]
2017-05-29 Навел порядок в файлах проекта, добавил файлы проекта MeW Pro
    [MeW.kicad_pcb, MeW.sch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]
2017-05-29 add dma-i2c reading support
2017-05-31 Add i2c dma&isr, remove slowly polling code
2017-06-10 add i2c eeprom support
2017-06-12 fix bugs and add usb cdc
    [mew.c, mew_usb_hid.c]
2017-06-13 Начал писать софтину для десктопа на жаве, начал пилить протокол для конфигурации через usb cdc.
2017-06-14 Мелкие правки
2017-06-19 add usb msd support\nРазработка пока приостановлена на недельку-другую - купил чипы с али, пришли глючные - отваливается usb. Заказал у офдилера, жду.
2017-06-19 add new hardware
    [MeW-Pro-v2.kicad_pcb, MeW-Pro-v2.sch, _saved_MeW-Pro-v2.sch]
2018-08-28 sync repo with gitlab
    [Gerber_BoardOutline.GKO, Gerber_BottomLayer.GBL, Gerber_BottomPasteMaskLayer.GBP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]
2018-10-22 add case and logo.svg
    [Case_mewboard_b.stl]
2019-03-06 add android app; add photos; add kicad sources for old board;
    [BOM-RU.ods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]
2020-05-19 fix firmware update sw
    [BOM-RU.ods, Case_mewboard_b.stl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]
2020-05-21 fix usb descriptors for composite device
    [display.c, mew_usb_hid.c]
